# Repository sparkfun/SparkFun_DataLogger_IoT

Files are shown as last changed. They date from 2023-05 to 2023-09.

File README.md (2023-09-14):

SparkFun DataLogger IoT
========================================

SparkFun DataLogger IoT (https://www.sparkfun.com/products/22462)

[*SparkFun DataLogger IoT (DEV-22462)*](https://www.sparkfun.com/products/22462)

<Basic description of the part.>

Repository Contents
-------------------

<!-- * **/Enclosure** - Enclosure files --> 
* **/Examples** - Test code 
* **/Hardware** - Eagle design files (.brd, .sch)
* **/Production** - Production panel files (.brd)

Documentation
--------------
* **[Hookup Guide](https://docs.sparkfun.com/SparkFun_DataLogger/)** - Basic hookup guide for the DataLogger IoT.
* **[Firmware](https://github.com/sparkfun/SparkFun_DataLogger/)** - Repo for the Datalogger IoT Firmware

Product Versions
----------------
* [DEV-22462](https://www.sparkfun.com/products/22462) - Initial Release

Version History
---------------
* v1.1 - Initial Release

License Information
-------------------

This hardware and the hardware test sketches contained in this GitHub repo are _**open source**_!

Please review the LICENSE.md file for license information. 

If you have any questions or concerns on licensing, please contact technical support on our [SparkFun forums](https://forum.sparkfun.com/viewforum.php?f=152).

Distributed as-is; no warranty is given.

- Your friends at SparkFun.

_<COLLABORATION CREDIT>_

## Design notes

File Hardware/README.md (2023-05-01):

SparkFun <PRODUCT NAME> Design Files
=====================================

The .sch and .brd files hare are Eagle CAD schematic and PCB design files from SparkFun Electronics.
A freeware version of Autodesk Eagle can be found [here](https://www.autodesk.com/products/eagle/free-download).

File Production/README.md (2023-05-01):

SparkFun <PRODUCT NAME> Production Files
=========================================

These are the production files SparkFun uses for printing PCBs.

License Information
-------------------
This product is open source! 

The hardware is released under [Creative Commons ShareAlike 4.0 International](https://creativecommons.org/licenses/by-sa/4.0/).

Please use, reuse, and modify these files as you see fit. Please maintain attribution to SparkFun Electronics and release anything derivative under the same license.

Distributed as-is; no warranty is given.

- Your friends at SparkFun.

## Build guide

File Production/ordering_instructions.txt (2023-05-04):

panel size, 116x155mm
PCB thickness, 1.6mm
number of layers, 4
controlled impedance, JLC7628
material, TG155
soldermask color, Red
silkscreen color, White
oz copper, 1oz
finish, HASL lead free
stencils, top+bottom
pcs per panel, 6
min trace width, 0.1524mm / 0.0060in
min drill size, 0.3000mm / 0.0118in
filename to layer stackup 1/2/3/4: GTL, GL2, GL3, GBL

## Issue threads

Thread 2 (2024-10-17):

Not possible to get higher accelerometer sampling rates using Datalogger IoT

Mohrlund, 2024-10-17:
### Subject of the issue
Not possible to get higher sample rates

### Your workbench
* What development board or microcontroller are you using? DataLogger IoT
* What version of hardware or breakout board are you using? See https://community.sparkfun.com/t/slow-sampling-rate-with-sparkfun-datalogger-iot-sparkfun-6dof-imu-breakout-ism330/61119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
* How is the breakout board wired to your microcontroller? QWIIK cable
* How is everything being powered? Tried both battery and lab agg
* Are there any additional details that may help us help you? See https://community.sparkfun.com/t/slow-sampling-rate-with-sparkfun-datalogger-iot-sparkfun-6dof-imu-breakout-ism330/61119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

### Steps to reproduce
Tell us how to reproduce this issue. Please post stripped down example code demonstrating your issue.
See https://community.sparkfun.com/t/slow-sampling-rate-with-sparkfun-datalogger-iot-sparkfun-6dof-imu-breakout-ism330/61119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

### Expected behavior
Tell us what should happen
I can't log data at the higher sampling rates available in the Datalogger IoT setup menu

### Actual behavior
Tell us what happens instead
See https://community.sparkfun.com/t/slow-sampling-rate-with-sparkfun-datalogger-iot-sparkfun-6dof-imu-breakout-ism330/61119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

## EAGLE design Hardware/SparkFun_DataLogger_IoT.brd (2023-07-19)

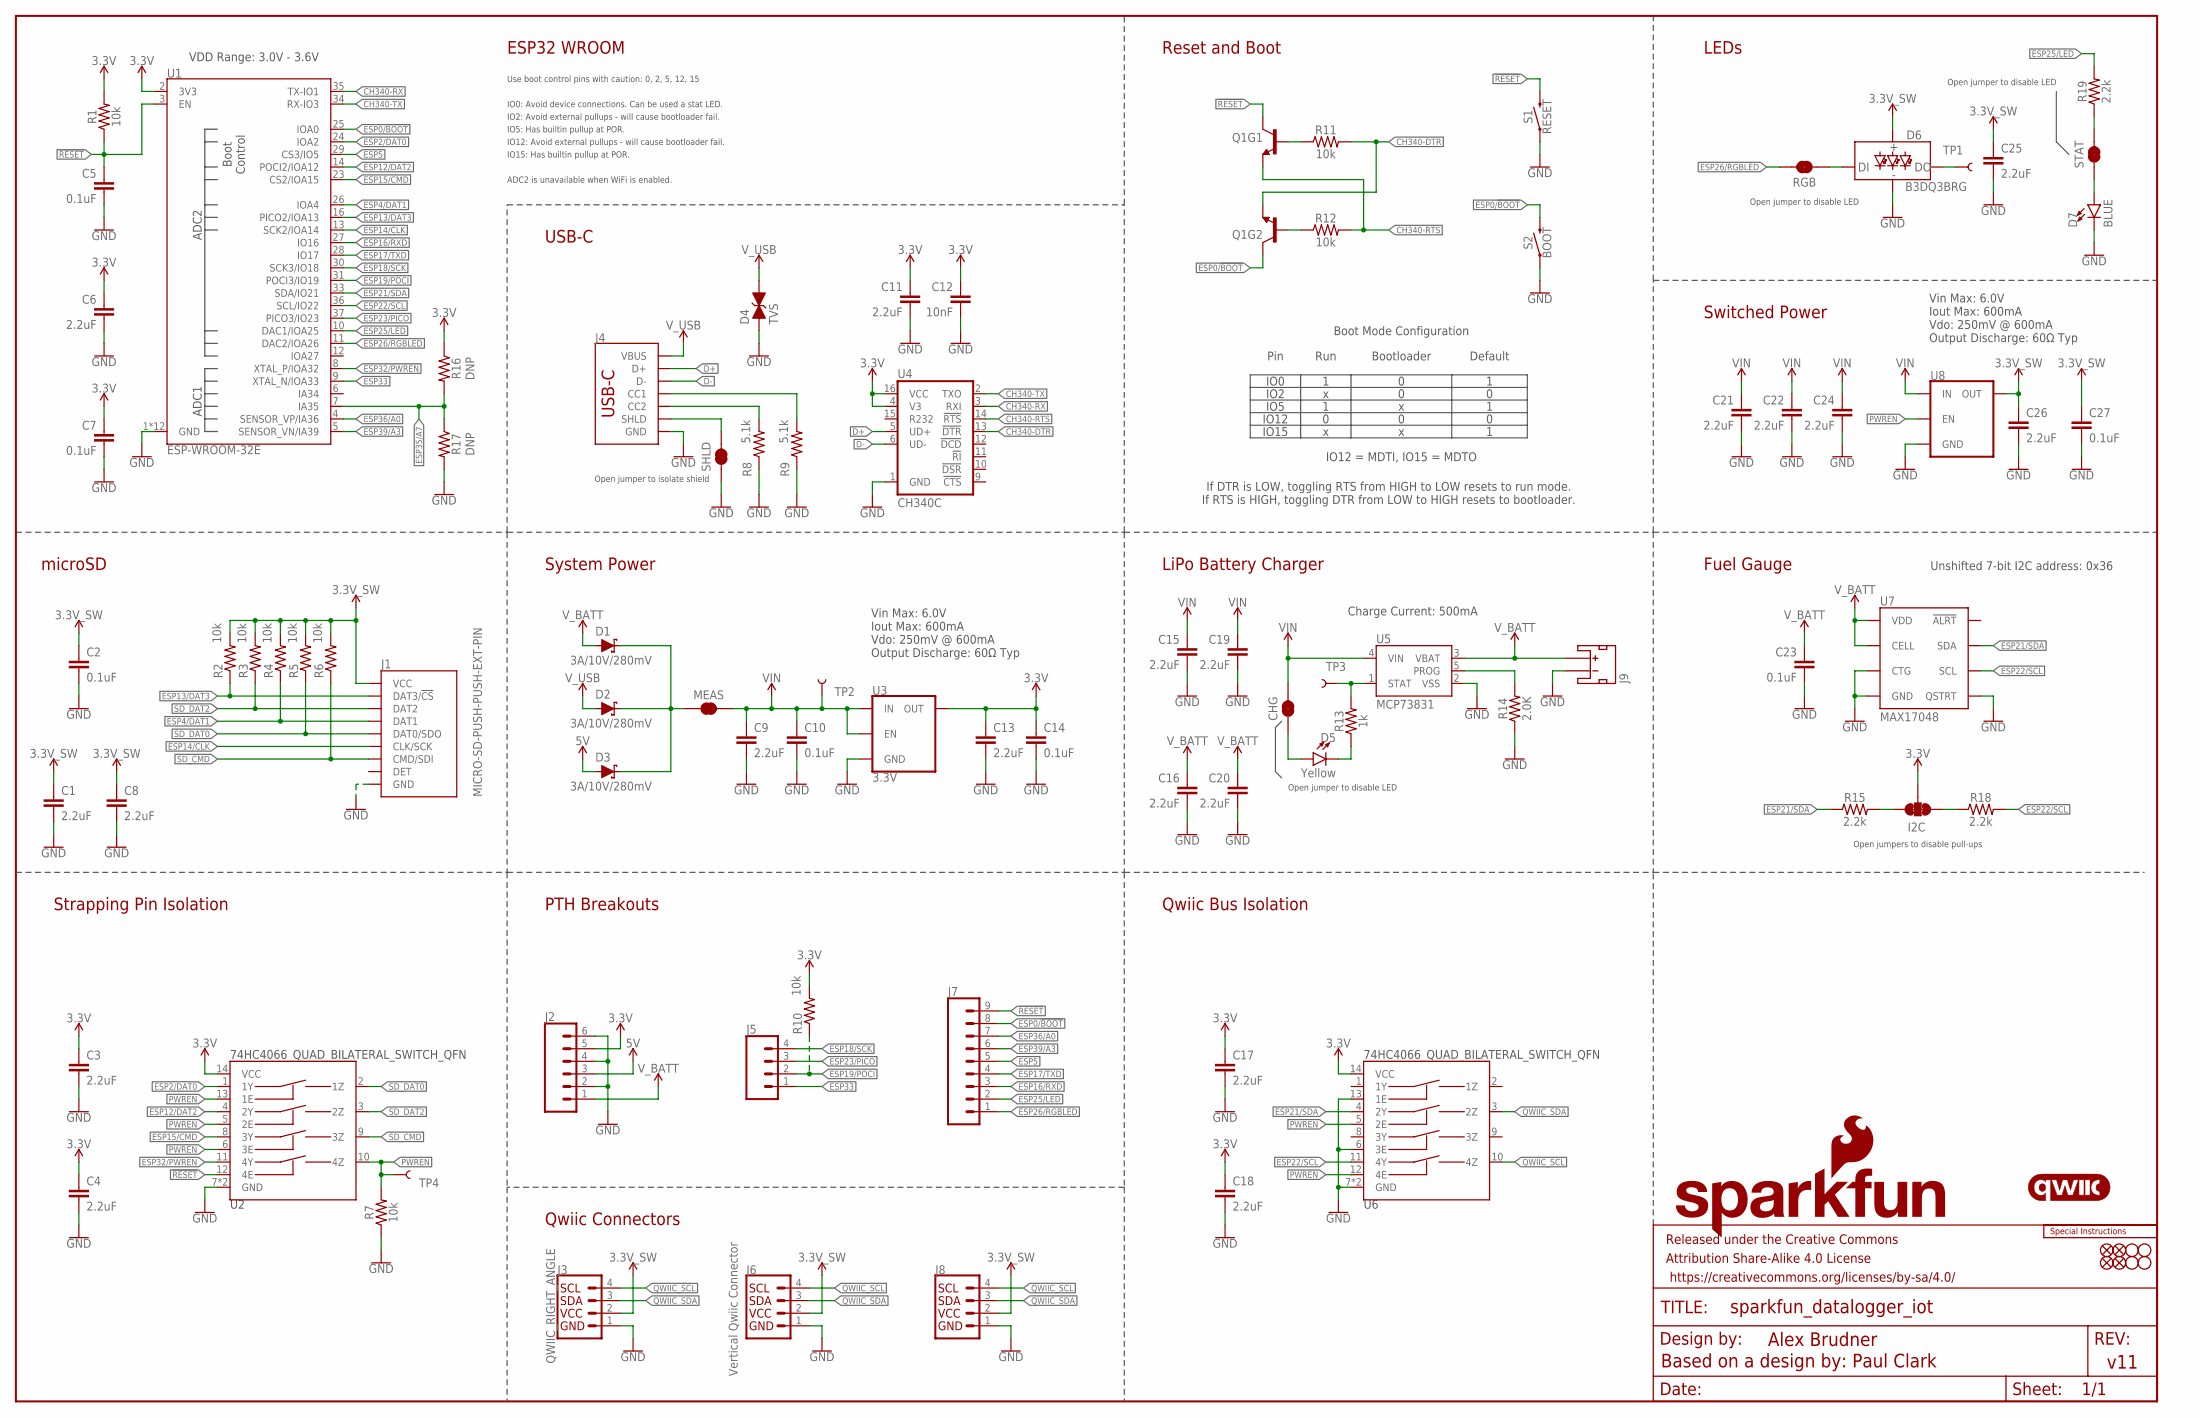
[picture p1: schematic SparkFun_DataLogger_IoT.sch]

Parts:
C1, C3, C4, C6, C8, C9, C11, C13, C15, C16, C17, C18, C19, C20, C21, C22, C24, C25, C26: 2.2uF; 0402-TIGHT
C2, C5, C7, C10, C14, C23, C27: 0.1uF; 0402-TIGHT
C12: 10nF; 0402-TIGHT
CHG: JUMPER-SMT_2_NC_TRACE_SILK; SMT-JUMPER_2_NC_TRACE_SILK
D1, D2, D3: 3A/10V/280mV; SOD-323
D4: TVS; 0603
D5: Yellow; LED-0603
D6: B3DQ3BRG
D7: BLUE; LED-0603
FD1, FD2, FD3, FD4: FIDUCIAL1X2; FIDUCIAL-1X2
FRAME1: FRAME-LEDGER; CREATIVE_COMMONS
H1, H2, H3, H4: STAND-OFFTIGHT; STAND-OFF-TIGHT
I2C: JUMPER-SMT_3_2-NC_TRACE_SILK; SMT-JUMPER_3_2-NC_TRACE_SILK
J1: MICRO-SD-PUSH-PUSH-EXT-PIN; MICROSD-EXTERNALPIN
J2: CONN_06NO_SILK_NO_POP; 1X06_NO_SILK
J3: QWIIC_RIGHT_ANGLE; JST04_1MM_RA
J4: USB_C_4-LAYER_PADS; USB-C-16P_4LAYER-PADS
J5: CONN_041X04_NO_SILK_NO_POP; 1X04_NO_SILK
J6: Vertical Qwiic Connector; JST04_1MM_VERT
J7: CONN_09NO_SILK; 1X09_NO_SILK
J8: I2C_STANDARD_NO_SILK; 1X04_NO_SILK
J9: JST_2MM_MALE; JST-2-SMD
LOGO1: SFE_LOGO_NAME.2_INCH; SFE_LOGO_NAME_.2
LOGO2: SFE_LOGO_FLAME.2_INCH; SFE_LOGO_FLAME_.2
LOGO3: SPECIAL_INSTRUCTIONS-ORDERING; ORDERING_INSTRUCTIONS
LOGO4: QWIIC_LOGO_6MM; QWIIC_6MM
MEAS: JUMPER-COMBO_2_NC_TRACE; COMBO-JUMPER_2_NC_TRACE
Q1: TRANS_NPN_DUAL-MBT3904DW1T1; SC70-6
R1, R2, R3, R4, R5, R6, R7, R10, R11, R12: 10k; 0402-TIGHT
R8, R9: 5.1k; 0402-TIGHT
R13: 1k; 0402-TIGHT
R14: 2.0K; 0402-TIGHT
R15, R18, R19: 2.2k; 0402-TIGHT
R16, R17: DNP; 0402-TIGHT_NO_CREAM
RGB: JUMPER-SMT_2_NC_TRACE_SILK; SMT-JUMPER_2_NC_TRACE_SILK
S1: RESET; TACTILE_SWITCH_SMD_RIGHT_ANGLE
S2: BOOT; TACTILE_SWITCH_SMD_RIGHT_ANGLE
SHLD: JUMPER-SMT_2_NC_TRACE_SILK; SMT-JUMPER_2_NC_TRACE_SILK
STAT: JUMPER-SMT_2_NC_TRACE_SILK; SMT-JUMPER_2_NC_TRACE_SILK
TP1, TP2, TP3, TP4: TEST-POINT3X5; PAD.03X.05
U1: ESP-WROOM-32E; ESP-WROOM-32D-NARROW
U2, U6: 74HC4066_QUAD_BILATERAL_SWITCH_QFN; 14-QFN
U3, U8: 3.3V; SOT23-5
U4: CH340C; SO016
U5: MCP73831; SOT23-5
U7: MAX17048; DFN-8

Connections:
3.3V: C3.1, C4.1, C6.1, C7.1, C11.1, C12.1, C13.1, C14.1, C17.1, C18.1, I2C.2, J2.5, R1.2, R10.2, R16.1, U1.2 (3V3), U2.14 (VCC), U3.5 (OUT), U4.4 (V3), U4.16 (VCC), U6.14 (VCC)
3.3V_SW: C1.1, C2.1, C8.1, C25.1, C26.1, C27.1, D6.2 (VCC), J1.4 (VCC), J3.2, J6.2, J8.2, R2.2, R3.2, R4.2, R5.2, R6.2, U8.5 (OUT)
5V: D3.A, J2.3
!RESET!: C5.1, J7.9, Q1.3 (C), R1.1, S1.2, U1.3 (EN), U2.12 (4E)
CH340-DTR: Q1.1 (E), R11.2, U4.13 (!DTR)
CH340-RTS: Q1.4 (E), R12.2, U4.14 (!RTS)
CH340-RX: U1.35 (TX-IO1), U4.3 (RXI)
CH340-TX: U1.34 (RX-IO3), U4.2 (TXO)
D+: J4.A6 (D+), J4.B6 (D+), U4.5 (UD+)
D-: J4.A7 (D-), J4.B7 (D-), U4.6 (UD-)
ESP0/!BOOT!: J7.8, Q1.6 (C), S2.2, U1.25 (IOA0)
ESP2/DAT0: U1.24 (IOA2), U2.1 (1Y)
ESP4/DAT1: J1.8 (DAT1), R4.1, U1.26 (IOA4)
ESP5: J7.5, U1.29 (CS3/IO5)
ESP12/DAT2: U1.14 (POCI2/IOA12), U2.4 (2Y)
ESP13/DAT3: J1.2 (DAT3/!CS!), R2.1, U1.16 (PICO2/IOA13)
ESP14/CLK: J1.5 (CLK/SCK), U1.13 (SCK2/IOA14)
ESP15/CMD: U1.23 (CS2/IOA15), U2.8 (3Y)
ESP16/RXD: J7.3, U1.27 (IO16)
ESP17/TXD: J7.4, U1.28 (IO17)
ESP18/SCK: J5.4, U1.30 (SCK3/IO18)
ESP19/POCI: J5.2, R10.1, U1.31 (POCI3/IO19)
ESP21/SDA: R15.1, U1.33 (SDA/IO21), U6.4 (2Y), U7.8 (SDA)
ESP22/SCL: R18.2, U1.36 (SCL/IO22), U6.11 (4Y), U7.7 (SCL)
ESP23/PICO: J5.3, U1.37 (PICO3/IO23)
ESP25/LED: J7.2, R19.2, U1.10 (DAC1/IOA25)
ESP26/RGBLED: J7.1, RGB.2, U1.11 (DAC2/IOA26)
ESP32/PWREN: U1.8 (XTAL_P/IOA32), U2.11 (4Y)
ESP33: J5.1, U1.9 (XTAL_N/IOA33)
ESP35/A7: R16.2, R17.1, U1.7 (IA35)
ESP36/A0: J7.7, U1.4 (SENSOR_VP/IA36)
ESP39/A3: J7.6, U1.5 (SENSOR_VN/IA39)
GND: C1.2, C2.2, C3.2, C4.2, C5.2, C6.2, C7.2, C8.2, C9.2, C10.2, C11.2, C12.2, C13.2, C14.2, C15.2, C16.2, C17.2, C18.2, C19.2, C20.2, C21.2, C22.2, C23.2, C24.2, C25.2, C26.2, C27.2, D4.1 (A), D6.1 (GND), D7.C, J1.6 (GND), J1.10 (GND), J1.11 (GND), J1.12 (GND), J1.13 (GND), J2.2, J2.4, J2.6, J3.1, J4.GND, J4.GND2 (GND), J6.1, J8.1, J9.1 (-), R7.1, R8.1, R9.1, R14.1, R17.2, S1.1, S2.1, SHLD.1, U1.1 (GND), U1.15 (GND), U1.38 (GND), U1.GND1 (GND), U1.GNDT1 (GND), U1.GNDT2 (GND), U1.GNDT3 (GND), U1.GNDT4 (GND), U1.GNDT5 (GND), U1.GNDT6 (GND), U1.GNDT7 (GND), U1.GNDT8 (GND), U2.7 (GND), U2.EPAD (GND), U3.2 (GND), U4.1 (GND), U5.2 (VSS), U6.6 (3E), U6.7 (GND), U6.13 (1E), U6.EPAD (GND), U7.1 (CTG), U7.4 (GND), U7.6 (QSTRT), U7.9 (GND), U8.2 (GND)
unnamed: J4.B5 (CC2), R8.2
unnamed: J4.A5 (CC1), R9.2
unnamed: D1.C, D2.C, D3.C, MEAS.1, MEAS.3 (1)
unnamed: Q1.2 (B), R12.1
unnamed: Q1.5 (B), R11.1
unnamed: R19.1, STAT.2
unnamed: D6.4 (DO), TP1.1
unnamed: CHG.1, D5.A
unnamed: D5.C, R13.1
unnamed: R13.2, TP3.1, U5.1 (STAT)
unnamed: R14.2, U5.5 (PROG)
unnamed: D6.3 (DI), RGB.1
unnamed: D7.A, STAT.1
unnamed: I2C.1, R18.1
unnamed: I2C.3, R15.2
PWREN: R7.2, TP4.1, U2.5 (2E), U2.6 (3E), U2.10 (4Z), U2.13 (1E), U6.5 (2E), U6.12 (4E), U8.3 (EN)
QWIIC_SCL: J3.4, J6.4, J8.4, U6.10 (4Z)
QWIIC_SDA: J3.3, J6.3, J8.3, U6.3 (2Z)
SD_CMD: J1.3 (CMD/SDI), R6.1, U2.9 (3Z)
SD_DAT0: J1.7 (DAT0/SDO), R5.1, U2.2 (1Z)
SD_DAT2: J1.1 (DAT2), R3.1, U2.3 (2Z)
SHIELD: J4.SHLD1 (SHLD), J4.SHLD2 (SHLD), J4.SHLD3 (SHLD), J4.SHLD4 (SHLD), SHLD.2
VIN: C9.1, C10.1, C15.1, C19.1, C21.1, C22.1, C24.1, CHG.2, MEAS.2, MEAS.4 (2), TP2.1, U3.1 (IN), U3.3 (EN), U5.4 (VIN), U8.1 (IN)
V_BATT: C16.1, C20.1, C23.1, D1.A, J2.1, J9.2 (+), U5.3 (VBAT), U7.2 (CELL), U7.3 (VDD)
V_USB: D2.A, D4.2 (C), J4.VBUS1 (VBUS), J4.VBUS2 (VBUS)

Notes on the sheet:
ESP32 WROOM
USB-C
Reset and Boot
LEDs
Switched Power
Fuel Gauge
LiPo Battery Charger
System Power
microSD
Strapping Pin Isolation
Qwiic Bus Isolation
PTH Breakouts
Charge Current: 500mA
VDD Range: 3.0V - 3.6V
Vin Max: 6.0V Iout Max: 600mA Vdo: 250mV @ 600mA Output Discharge: 60Ω Typ
If DTR is LOW, toggling RTS from HIGH to LOW resets to run mode. If RTS is HIGH, toggling DTR from LOW to HIGH resets to bootloader.
Pin
IO0
IO2
IO12
IO15
IO5
Run
Bootloader
Default
IO12 = MDTI, IO15 = MDTO
Boot Mode Configuration
IO0: Avoid device connections. Can be used a stat LED.
ADC2 is unavailable when WiFi is enabled.
IO12: Avoid external pullups - will cause bootloader fail.
Use boot control pins with caution: 0, 2, 5, 12, 15
IO2: Avoid external pullups - will cause bootloader fail.
IO15: Has builtin pullup at POR.
IO5: Has builtin pullup at POR.
Open jumpers to disable pull-ups
Open jumper to disable LED
Open jumper to isolate shield
Based on a design by: Paul Clark
Qwiic Connectors
TP2

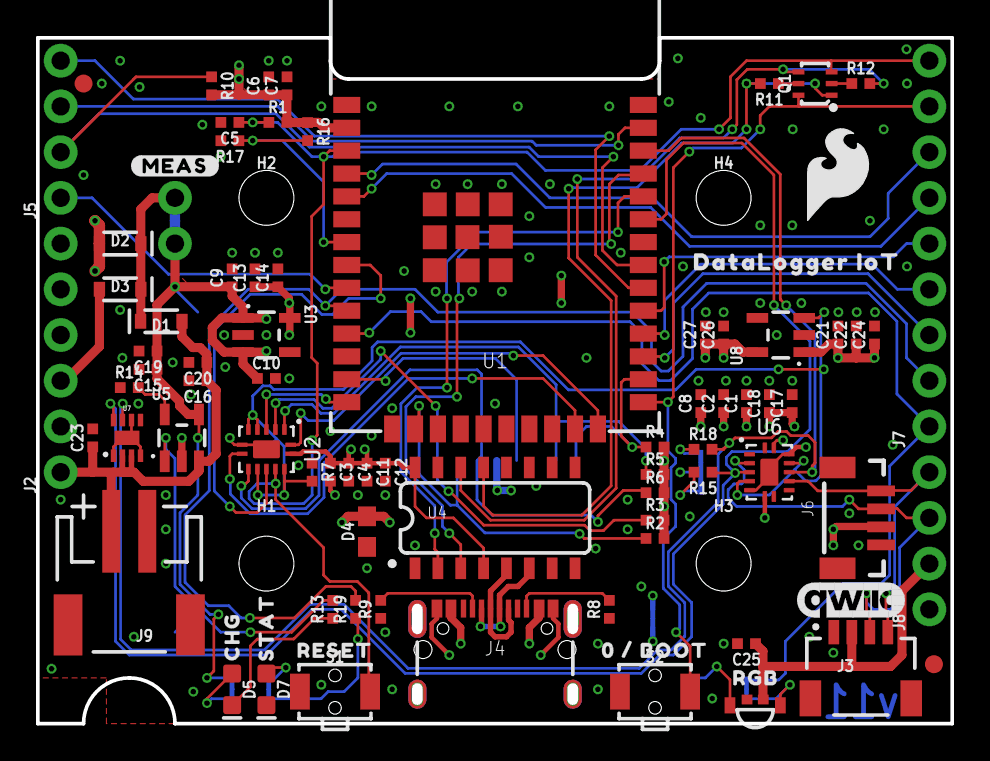
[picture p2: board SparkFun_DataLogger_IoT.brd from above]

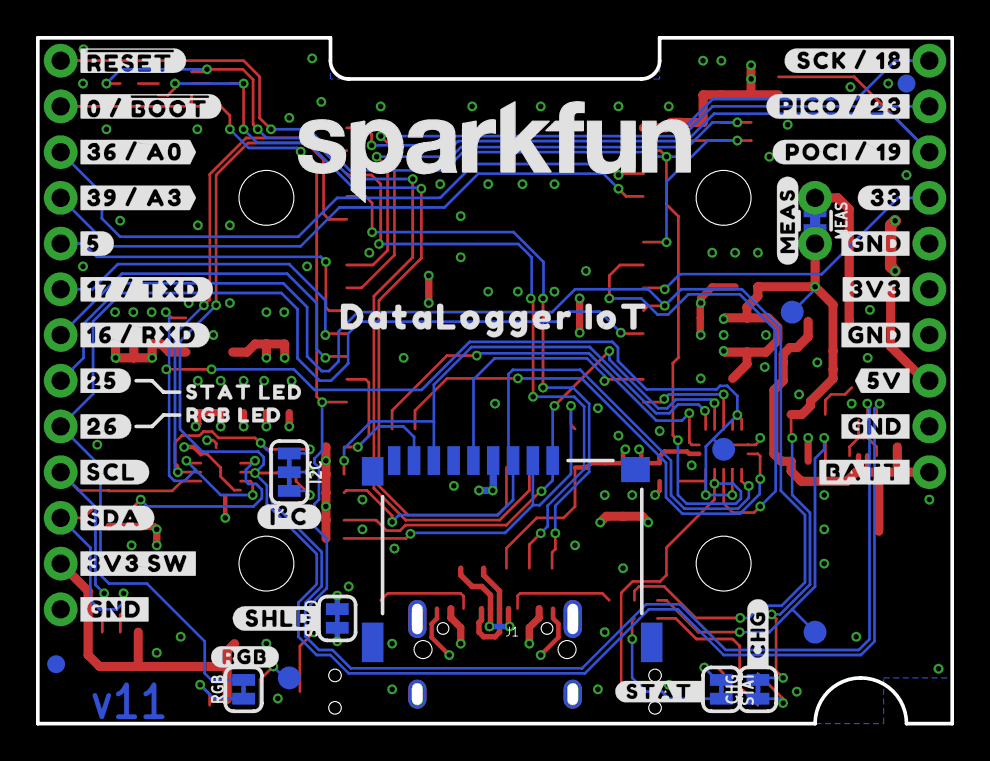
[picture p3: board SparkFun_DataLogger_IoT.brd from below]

Board: 4 copper layers, 50.8 x 38.1 mm, 136 parts (47 on the bottom side), 58 nets.

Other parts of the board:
U$1: DATALOGGER_IOT5
U$2: RESET0
U$3: STAT0
U$4: CHG0
U$5: #STAT_#0
U$6: #RGB#0
U$7: 0_#_BOOT0
U$8: #_CHG#0
U$9, U$10: #MEAS#0
U$11: RGB0
U$12: #5#0
U$13: SFE_LOGO_FLAME_STOP_.1
U$14: DATALOGGER_IOT2
U$16: ##RESET##0
U$17: #0_#_#BOOT##0
U$18: #36_#_A0#0
U$19: #39_#_A3#0
U$21: #17_#_TXD#0
U$22: #16_#_RXD#0
U$23: #25#0
U$24: #26#0
U$25: #SCL#0
U$26: #SDA#0
U$27: #3V3_SW#0
U$28: #GND#0
U$29, U$30, U$31: #GND#1
U$32: #BATT#0
U$33: #5V#0
U$34: #3V3#0
U$35: #33#0
U$36: #POCI_#_19#0
U$37: #PICO_#_23#0
U$38: #SCK_#_18#0
U$45: #SHLD#0
U$46: #I�C#0
U$47: STAT_LED0
U$48: RGB_LED0

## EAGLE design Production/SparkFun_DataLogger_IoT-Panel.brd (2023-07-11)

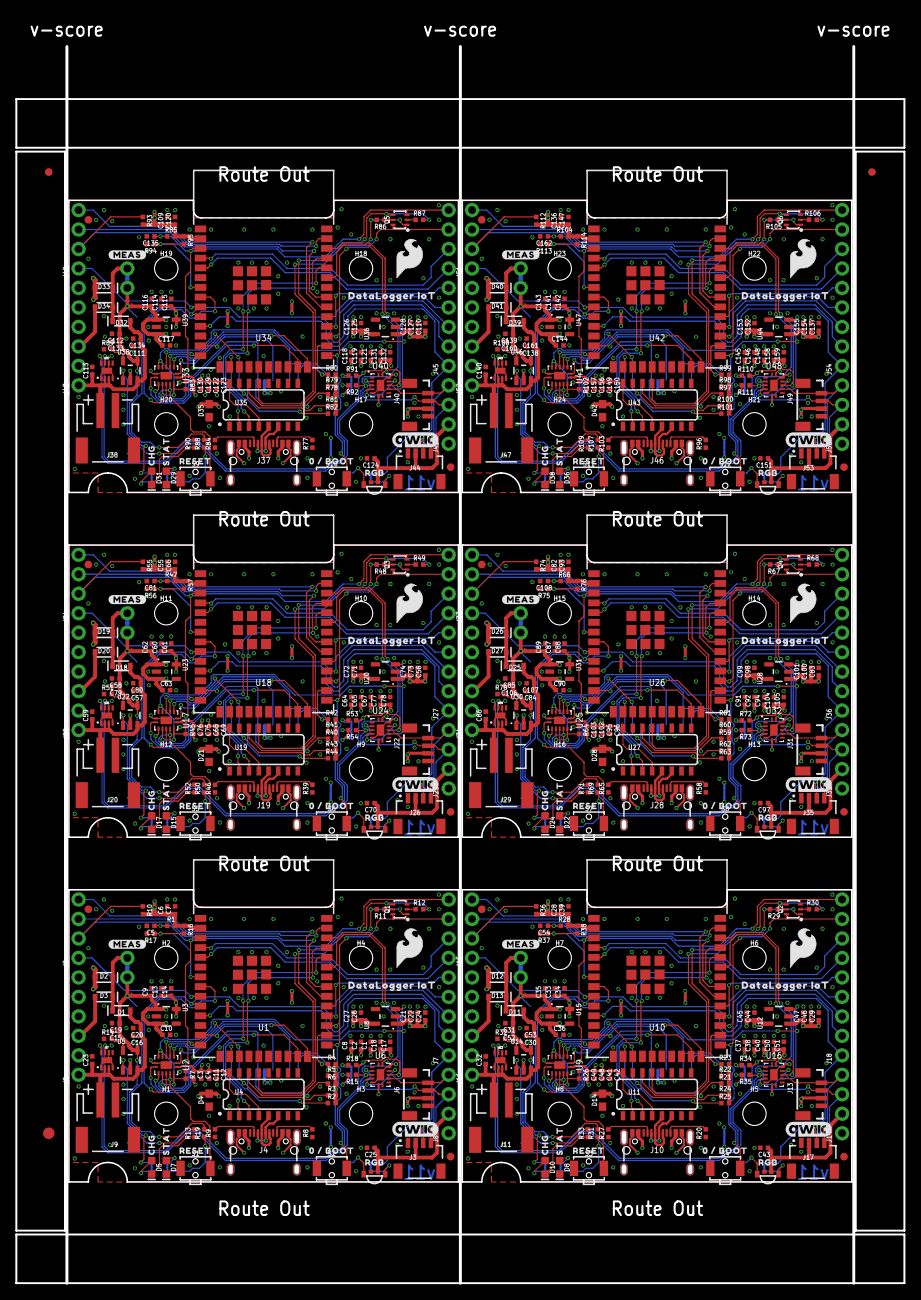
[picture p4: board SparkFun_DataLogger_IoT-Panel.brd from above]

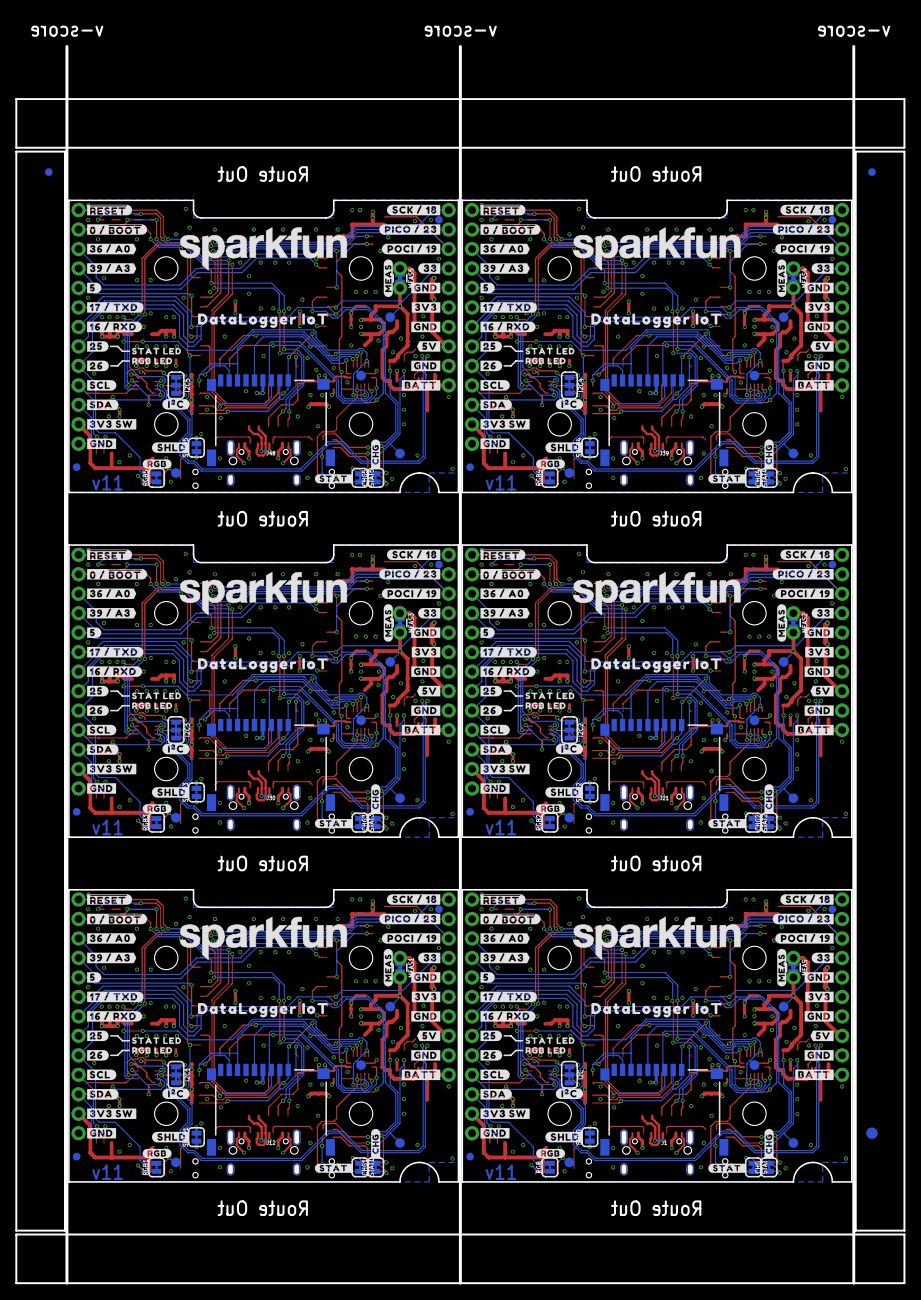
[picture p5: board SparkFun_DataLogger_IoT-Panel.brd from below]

Board: 4 copper layers, 115.8 x 161.3 mm, 810 parts (285 on the bottom side), 348 nets.

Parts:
C1, C3, C4, C6, C8, C9, C11, C13, C15, C16, C17, C18, C19, C20, C21, C22, C24, C25, C26, C28, C29, C30, C31, C33, C35, C37, C40, C41, C43, C44, C46, C47, C48, C49, C50, C51, C52, C53, C55, C56, C57, C58, C60, C62, C64, C67, C68, C70, C71, C73, C74, C75, C76, C77, C78, C79, C80, C82, C83, C84, C85, C87, C89, C91, C94, C95, C97, C98, C100, C101, C102, C103, C104, C105, C106, C107, C109, C110, C111, C112, C114, C116, C118, C121, C122, C124, C125, C127, C128, C129, C130, C131, C132, C133, C134, C136, C137, C138, C139, C141, C143, C145, C148, C149, C151, C152, C154, C155, C156, C157, C158, C159, C160, C161: 2.2uF; 0402-TIGHT
C2, C5, C7, C10, C14, C23, C27, C32, C34, C36, C38, C39, C45, C54, C59, C61, C63, C65, C66, C72, C81, C86, C88, C90, C92, C93, C99, C108, C113, C115, C117, C119, C120, C126, C135, C140, C142, C144, C146, C147, C153, C162: 0.1uF; 0402-TIGHT
C12, C42, C69, C96, C123, C150: 10nF; 0402-TIGHT
CHG, CHG1, CHG2, CHG3, CHG4, CHG5: JUMPER-SMT_2_NC_TRACE_SILK; SMT-JUMPER_2_NC_TRACE_SILK
D1, D2, D3, D11, D12, D13, D18, D19, D20, D25, D26, D27, D32, D33, D34, D39, D40, D41: 3A/10V/280mV; SOD-323
D4, D14, D21, D28, D35, D42: TVS; 0603
D5, D10, D17, D24, D31, D38: Yellow; LED-0603
D6, D9, D16, D23, D30, D37: B3DQ3BRG
D7, D8, D15, D22, D29, D36: BLUE; LED-0603
E$1, E$2, E$3, E$4: FIDUCIAL-1X2
E$5, E$6: FIDUCIAL-1.5X3
FD1, FD2, FD3, FD4, FD5, FD6, FD7, FD8, FD9, FD10, FD11, FD12, FD13, FD14, FD15, FD16, FD17, FD18, FD19, FD20, FD21, FD22, FD23, FD24: FIDUCIAL1X2; FIDUCIAL-1X2
H1, H2, H3, H4, H5, H6, H7, H8, H9, H10, H11, H12, H13, H14, H15, H16, H17, H18, H19, H20, H21, H22, H23, H24: STAND-OFFTIGHT; STAND-OFF-TIGHT
I2C, I2C1, I2C2, I2C3, I2C4, I2C5: JUMPER-SMT_3_2-NC_TRACE_SILK; SMT-JUMPER_3_2-NC_TRACE_SILK
J1, J12, J21, J30, J39, J48: MICRO-SD-PUSH-PUSH-EXT-PIN; MICROSD-EXTERNALPIN
J2, J16, J25, J34, J43, J52: 1X06_NO_SILK
J3, J17, J26, J35, J44, J53: QWIIC_RIGHT_ANGLE; JST04_1MM_RA
J4, J10, J19, J28, J37, J46: USB-C-16P_4LAYER-PADS
J5, J8, J14, J15, J23, J24, J32, J33, J41, J42, J50, J51: 1X04_NO_SILK
J6, J13, J22, J31, J40, J49: Vertical Qwiic Connector; JST04_1MM_VERT
J7, J18, J27, J36, J45, J54: 1X09_NO_SILK
J9, J11, J20, J29, J38, J47: JST-2-SMD
LOGO1, LOGO5, LOGO8, LOGO11, LOGO14, LOGO17: SFE_LOGO_NAME.2_INCH; SFE_LOGO_NAME_.2
LOGO2, LOGO6, LOGO9, LOGO12, LOGO15, LOGO18: SFE_LOGO_FLAME.2_INCH; SFE_LOGO_FLAME_.2
LOGO3, LOGO4, LOGO7, LOGO10, LOGO13, LOGO16: QWIIC_LOGO_6MM; QWIIC_6MM
MEAS, MEAS1, MEAS2, MEAS3, MEAS4, MEAS5: JUMPER-COMBO_2_NC_TRACE; COMBO-JUMPER_2_NC_TRACE
Q1, Q2, Q3, Q4, Q5, Q6: SC70-6
R1, R2, R3, R4, R5, R6, R7, R10, R11, R12, R21, R22, R23, R24, R25, R26, R28, R29, R30, R36, R40, R41, R42, R43, R44, R45, R47, R48, R49, R55, R59, R60, R61, R62, R63, R64, R66, R67, R68, R74, R78, R79, R80, R81, R82, R83, R85, R86, R87, R93, R97, R98, R99, R100, R101, R102, R104, R105, R106, R112: 10k; 0402-TIGHT
R8, R9, R20, R27, R39, R46, R58, R65, R77, R84, R96, R103: 5.1k; 0402-TIGHT
R13, R33, R52, R71, R90, R109: 1k; 0402-TIGHT
R14, R32, R51, R70, R89, R108: 2.0K; 0402-TIGHT
R15, R18, R19, R31, R34, R35, R50, R53, R54, R69, R72, R73, R88, R91, R92, R107, R110, R111: 2.2k; 0402-TIGHT
R16, R38, R57, R76, R95, R114: 100k; 0402-TIGHT
R17, R37, R56, R75, R94, R113: 9.1K; 0402-TIGHT
RGB, RGB1, RGB2, RGB3, RGB4, RGB5: JUMPER-SMT_2_NC_TRACE_SILK; SMT-JUMPER_2_NC_TRACE_SILK
S1, S3, S5, S7, S9, S11: RESET; TACTILE_SWITCH_SMD_RIGHT_ANGLE
S2, S4, S6, S8, S10, S12: BOOT; TACTILE_SWITCH_SMD_RIGHT_ANGLE
SHLD, SHLD1, SHLD2, SHLD3, SHLD4, SHLD5: JUMPER-SMT_2_NC_TRACE_SILK; SMT-JUMPER_2_NC_TRACE_SILK
STAT, STAT1, STAT2, STAT3, STAT4, STAT5: JUMPER-SMT_2_NC_TRACE_SILK; SMT-JUMPER_2_NC_TRACE_SILK
TP1, TP2, TP3, TP4, TP5, TP6, TP7, TP8, TP9, TP10, TP11, TP12, TP13, TP14, TP15, TP16, TP17, TP18, TP19, TP20, TP21, TP22, TP23, TP24: TEST-POINT3X5; PAD.03X.05
U1, U10, U18, U26, U34, U42: ESP-WROOM-32E; ESP-WROOM-32D-NARROW
U2, U6, U9, U16, U17, U24, U25, U32, U33, U40, U41, U48: 74HC4066_QUAD_BILATERAL_SWITCH_QFN; 14-QFN
U3, U8, U12, U15, U20, U23, U28, U31, U36, U39, U44, U47: XC6222B331MR-G; SOT23-5
U4, U11, U19, U27, U35, U43: CH340C; SO016
U5, U14, U22, U30, U38, U46: MCP73831; SOT23-5
U7, U13, U21, U29, U37, U45: MAX17048; DFN-8
U$1, U$79, U$119, U$159, U$199, U$239: DATALOGGER_IOT5
U$2, U$15, U$81, U$121, U$161, U$201: RESET0
U$3, U$20, U$82, U$122, U$162, U$202: STAT0
U$4, U$39, U$83, U$123, U$163, U$203: CHG0
U$5, U$72, U$112, U$152, U$192, U$232: #STAT_#0
U$6, U$73, U$113, U$153, U$193, U$233: #RGB#0
U$7, U$70, U$110, U$150, U$190, U$230: 0_#_BOOT0
U$8, U$71, U$111, U$151, U$191, U$231: #_CHG#0
U$9, U$10, U$74, U$75, U$114, U$115, U$154, U$155, U$194, U$195, U$234, U$235: #MEAS#0
U$11, U$76, U$116, U$156, U$196, U$236: RGB0
U$12, U$80, U$120, U$160, U$200, U$240: #5#0
U$13, U$77, U$117, U$157, U$197, U$237: SFE_LOGO_FLAME_STOP_.1
U$14, U$78, U$118, U$158, U$198, U$238: DATALOGGER_IOT2
U$16, U$40, U$84, U$124, U$164, U$204: ##RESET##0
U$17, U$41, U$85, U$125, U$165, U$205: #0_#_#BOOT##0
U$18, U$42, U$86, U$126, U$166, U$206: #36_#_A0#0
U$19, U$43, U$87, U$127, U$167, U$207: #39_#_A3#0
U$21, U$44, U$88, U$128, U$168, U$208: #17_#_TXD#0
U$22, U$49, U$89, U$129, U$169, U$209: #16_#_RXD#0
U$23, U$50, U$90, U$130, U$170, U$210: #25#0
U$24, U$51, U$91, U$131, U$171, U$211: #26#0
U$25, U$52, U$92, U$132, U$172, U$212: #SCL#0
U$26, U$53, U$93, U$133, U$173, U$213: #SDA#0
U$27, U$54, U$94, U$134, U$174, U$214: #3V3_SW#0
U$28, U$55, U$95, U$135, U$175, U$215: #GND#0
U$29, U$30, U$31, U$56, U$57, U$58, U$96, U$97, U$98, U$136, U$137, U$138, U$176, U$177, U$178, U$216, U$217, U$218: #GND#1
U$32, U$59, U$99, U$139, U$179, U$219: #BATT#0
U$33, U$60, U$100, U$140, U$180, U$220: #5V#0
U$34, U$61, U$101, U$141, U$181, U$221: #3V3#0
U$35, U$62, U$102, U$142, U$182, U$222: #33#0
U$36, U$63, U$103, U$143, U$183, U$223: #POCI_#_19#0
U$37, U$64, U$104, U$144, U$184, U$224: #PICO_#_23#0
U$38, U$65, U$105, U$145, U$185, U$225: #SCK_#_18#0
U$45, U$66, U$106, U$146, U$186, U$226: #SHLD#0
U$46, U$67, U$107, U$147, U$187, U$227: #I�C#0
U$47, U$68, U$108, U$148, U$188, U$228: STAT_LED0
U$48, U$69, U$109, U$149, U$189, U$229: RGB_LED0

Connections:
3.3V: C3.1, C4.1, C6.1, C7.1, C11.1, C12.1, C13.1, C14.1, C17.1, C18.1, I2C.2, J2.5, R1.2, R10.2, R16.1, U1.2, U2.14, U3.5, U4.4, U4.16, U6.14
3.3V1: C28.1, C33.1, C34.1, C39.1, C41.1, C42.1, C48.1, C49.1, C50.1, C51.1, I2C1.2, J16.5, R28.2, R36.2, R38.1, U9.14, U10.2, U11.4, U11.16, U15.5, U16.14
3.3V2: C55.1, C60.1, C61.1, C66.1, C68.1, C69.1, C75.1, C76.1, C77.1, C78.1, I2C2.2, J25.5, R47.2, R55.2, R57.1, U17.14, U18.2, U19.4, U19.16, U23.5, U24.14
3.3V3: C82.1, C87.1, C88.1, C93.1, C95.1, C96.1, C102.1, C103.1, C104.1, C105.1, I2C3.2, J34.5, R66.2, R74.2, R76.1, U25.14, U26.2, U27.4, U27.16, U31.5, U32.14
3.3V4: C109.1, C114.1, C115.1, C120.1, C122.1, C123.1, C129.1, C130.1, C131.1, C132.1, I2C4.2, J43.5, R85.2, R93.2, R95.1, U33.14, U34.2, U35.4, U35.16, U39.5, U40.14
3.3V5: C136.1, C141.1, C142.1, C147.1, C149.1, C150.1, C156.1, C157.1, C158.1, C159.1, I2C5.2, J52.5, R104.2, R112.2, R114.1, U41.14, U42.2, U43.4, U43.16, U47.5, U48.14
3.3V_SW: C1.1, C2.1, C8.1, C25.1, C26.1, C27.1, D6.2, J1.4, J3.2, J6.2, J8.2, R2.2, R3.2, R4.2, R5.2, R6.2, U8.5
3.3V_SW1: C37.1, C38.1, C40.1, C43.1, C44.1, C45.1, D9.2, J12.4, J13.2, J14.2, J17.2, R21.2, R22.2, R23.2, R24.2, R25.2, U12.5
3.3V_SW2: C64.1, C65.1, C67.1, C70.1, C71.1, C72.1, D16.2, J21.4, J22.2, J23.2, J26.2, R40.2, R41.2, R42.2, R43.2, R44.2, U20.5
3.3V_SW3: C91.1, C92.1, C94.1, C97.1, C98.1, C99.1, D23.2, J30.4, J31.2, J32.2, J35.2, R59.2, R60.2, R61.2, R62.2, R63.2, U28.5
3.3V_SW4: C118.1, C119.1, C121.1, C124.1, C125.1, C126.1, D30.2, J39.4, J40.2, J41.2, J44.2, R78.2, R79.2, R80.2, R81.2, R82.2, U36.5
3.3V_SW5: C145.1, C146.1, C148.1, C151.1, C152.1, C153.1, D37.2, J48.4, J49.2, J50.2, J53.2, R97.2, R98.2, R99.2, R100.2, R101.2, U44.5
5V: D3.A, J2.3
5V1: D13.A, J16.3
5V2: D20.A, J25.3
5V3: D27.A, J34.3
5V4: D34.A, J43.3
5V5: D41.A, J52.3
!RESET!: C5.1, J7.9, Q1.3, R1.1, S1.2, U1.3, U2.12
!RESET!1: C54.1, J18.9, Q2.3, R28.1, S3.2, U9.12, U10.3
!RESET!2: C81.1, J27.9, Q3.3, R47.1, S5.2, U17.12, U18.3
!RESET!3: C108.1, J36.9, Q4.3, R66.1, S7.2, U25.12, U26.3
!RESET!4: C135.1, J45.9, Q5.3, R85.1, S9.2, U33.12, U34.3
!RESET!5: C162.1, J54.9, Q6.3, R104.1, S11.2, U41.12, U42.3
CH340-DTR: Q1.1, R11.2, U4.13
CH340-DTR1: Q2.1, R29.2, U11.13
CH340-DTR2: Q3.1, R48.2, U19.13
CH340-DTR3: Q4.1, R67.2, U27.13
CH340-DTR4: Q5.1, R86.2, U35.13
CH340-DTR5: Q6.1, R105.2, U43.13
CH340-RTS: Q1.4, R12.2, U4.14
CH340-RTS1: Q2.4, R30.2, U11.14
CH340-RTS2: Q3.4, R49.2, U19.14
CH340-RTS3: Q4.4, R68.2, U27.14
CH340-RTS4: Q5.4, R87.2, U35.14
CH340-RTS5: Q6.4, R106.2, U43.14
CH340-RX: U1.35, U4.3
CH340-RX1: U10.35, U11.3
CH340-RX2: U18.35, U19.3
CH340-RX3: U26.35, U27.3
CH340-RX4: U34.35, U35.3
CH340-RX5: U42.35, U43.3
CH340-TX: U1.34, U4.2
CH340-TX1: U10.34, U11.2
CH340-TX2: U18.34, U19.2
CH340-TX3: U26.34, U27.2
CH340-TX4: U34.34, U35.2
CH340-TX5: U42.34, U43.2
D+: J4.A6, J4.B6, U4.5
D+1: J10.A6, J10.B6, U11.5
D+2: J19.A6, J19.B6, U19.5
D+3: J28.A6, J28.B6, U27.5
D+4: J37.A6, J37.B6, U35.5
D+5: J46.A6, J46.B6, U43.5
D-: J4.A7, J4.B7, U4.6
D-1: J10.A7, J10.B7, U11.6
D-2: J19.A7, J19.B7, U19.6
D-3: J28.A7, J28.B7, U27.6
D-4: J37.A7, J37.B7, U35.6
D-5: J46.A7, J46.B7, U43.6
ESP0/!BOOT!: J7.8, Q1.6, S2.2, U1.25
ESP0/!BOOT!1: J18.8, Q2.6, S4.2, U10.25
ESP0/!BOOT!2: J27.8, Q3.6, S6.2, U18.25
ESP0/!BOOT!3: J36.8, Q4.6, S8.2, U26.25
ESP0/!BOOT!4: J45.8, Q5.6, S10.2, U34.25
ESP0/!BOOT!5: J54.8, Q6.6, S12.2, U42.25
ESP1: J15.1, U10.9
ESP2: J18.5, U10.29
ESP2/DAT0: U1.24, U2.1
ESP2/DAT1: U9.1, U10.24
ESP2/DAT2: U17.1, U18.24
ESP2/DAT3: U25.1, U26.24
ESP2/DAT4: U33.1, U34.24
ESP2/DAT5: U41.1, U42.24
ESP3: J24.1, U18.9
ESP4: J27.5, U18.29
ESP4/DAT1: J1.8, R4.1, U1.26
ESP4/DAT2: J12.8, R23.1, U10.26
ESP4/DAT3: J21.8, R42.1, U18.26
ESP4/DAT4: J30.8, R61.1, U26.26
ESP4/DAT5: J39.8, R80.1, U34.26
ESP4/DAT6: J48.8, R99.1, U42.26
ESP5: J7.5, U1.29
ESP6: J33.1, U26.9
ESP7: J36.5, U26.29
ESP8: J42.1, U34.9
ESP9: J45.5, U34.29
ESP10: J51.1, U42.9
ESP11: J54.5, U42.29
ESP12/DAT1: U9.4, U10.14
ESP12/DAT2: U1.14, U2.4
ESP12/DAT3: U17.4, U18.14
ESP12/DAT4: U25.4, U26.14
ESP12/DAT5: U33.4, U34.14
ESP12/DAT6: U41.4, U42.14
ESP13/DAT1: J12.2, R25.1, U10.16
ESP13/DAT2: J21.2, R44.1, U18.16
ESP13/DAT3: J1.2, R2.1, U1.16
ESP13/DAT4: J30.2, R63.1, U26.16
ESP13/DAT5: J39.2, R82.1, U34.16
ESP13/DAT6: J48.2, R101.1, U42.16
ESP14/CLK: J1.5, U1.13
ESP14/CLK1: J12.5, U10.13
ESP14/CLK2: J21.5, U18.13
ESP14/CLK3: J30.5, U26.13
ESP14/CLK4: J39.5, U34.13
ESP14/CLK5: J48.5, U42.13
ESP15/CMD: U1.23, U2.8
ESP15/CMD1: U9.8, U10.23
ESP15/CMD2: U17.8, U18.23
ESP15/CMD3: U25.8, U26.23
ESP15/CMD4: U33.8, U34.23
ESP15/CMD5: U41.8, U42.23
ESP16/RXD: J7.3, U1.27
ESP16/RXD1: J18.3, U10.27
ESP16/RXD2: J27.3, U18.27
ESP16/RXD3: J36.3, U26.27
ESP16/RXD4: J45.3, U34.27
ESP16/RXD5: J54.3, U42.27
ESP17/TXD: J7.4, U1.28
ESP17/TXD1: J18.4, U10.28
ESP17/TXD2: J27.4, U18.28
ESP17/TXD3: J36.4, U26.28
ESP17/TXD4: J45.4, U34.28
ESP17/TXD5: J54.4, U42.28
ESP18/SCK: J5.4, U1.30
ESP18/SCK1: J15.4, U10.30
ESP18/SCK2: J24.4, U18.30
ESP18/SCK3: J33.4, U26.30
ESP18/SCK4: J42.4, U34.30
ESP18/SCK5: J51.4, U42.30
ESP19/POCI: J5.2, R10.1, U1.31
ESP19/POCI1: J15.2, R36.1, U10.31
ESP19/POCI2: J24.2, R55.1, U18.31
ESP19/POCI3: J33.2, R74.1, U26.31
ESP19/POCI4: J42.2, R93.1, U34.31
ESP19/POCI5: J51.2, R112.1, U42.31
ESP21/SDA: R15.1, U1.33, U6.4, U7.8
ESP21/SDA1: R35.1, U10.33, U13.8, U16.4
ESP21/SDA2: R54.1, U18.33, U21.8, U24.4
ESP21/SDA3: R73.1, U26.33, U29.8, U32.4
ESP21/SDA4: R92.1, U34.33, U37.8, U40.4
ESP21/SDA5: R111.1, U42.33, U45.8, U48.4
ESP22/SCL: R18.2, U1.36, U6.11, U7.7
ESP22/SCL1: R34.2, U10.36, U13.7, U16.11
ESP22/SCL2: R53.2, U18.36, U21.7, U24.11
ESP22/SCL3: R72.2, U26.36, U29.7, U32.11
ESP22/SCL4: R91.2, U34.36, U37.7, U40.11
ESP22/SCL5: R110.2, U42.36, U45.7, U48.11
ESP23/PICO: J5.3, U1.37
ESP23/PICO1: J15.3, U10.37
ESP23/PICO2: J24.3, U18.37
ESP23/PICO3: J33.3, U26.37
ESP23/PICO4: J42.3, U34.37
ESP23/PICO5: J51.3, U42.37
ESP25/LED: J7.2, R19.2, U1.10
ESP25/LED1: J18.2, R31.2, U10.10
ESP25/LED2: J27.2, R50.2, U18.10
ESP25/LED3: J36.2, R69.2, U26.10
ESP25/LED4: J45.2, R88.2, U34.10
ESP25/LED5: J54.2, R107.2, U42.10
ESP26/RGBLED: J7.1, RGB.2, U1.11
ESP26/RGBLED1: J18.1, RGB1.2, U10.11
ESP26/RGBLED2: J27.1, RGB2.2, U18.11
ESP26/RGBLED3: J36.1, RGB3.2, U26.11
ESP26/RGBLED4: J45.1, RGB4.2, U34.11
ESP26/RGBLED5: J54.1, RGB5.2, U42.11
ESP32/PWREN: U1.8, U2.11
ESP32/PWREN1: U9.11, U10.8
ESP32/PWREN2: U17.11, U18.8
ESP32/PWREN3: U25.11, U26.8
ESP32/PWREN4: U33.11, U34.8
ESP32/PWREN5: U41.11, U42.8
ESP33: J5.1, U1.9
ESP35/A1: R37.1, R38.2, U10.7
ESP35/A2: R56.1, R57.2, U18.7
ESP35/A3: R75.1, R76.2, U26.7
ESP35/A4: R94.1, R95.2, U34.7
ESP35/A5: R113.1, R114.2, U42.7
ESP35/A7: R16.2, R17.1, U1.7
ESP36/A0: J7.7, U1.4
ESP36/A1: J18.7, U10.4
ESP36/A2: J27.7, U18.4
ESP36/A3: J36.7, U26.4
ESP36/A4: J45.7, U34.4
ESP36/A5: J54.7, U42.4
ESP39/A1: J18.6, U10.5
ESP39/A2: J27.6, U18.5
ESP39/A3: J7.6, U1.5
ESP39/A4: J36.6, U26.5
ESP39/A5: J45.6, U34.5
ESP39/A6: J54.6, U42.5
GND: C1.2, C2.2, C3.2, C4.2, C5.2, C6.2, C7.2, C8.2, C9.2, C10.2, C11.2, C12.2, C13.2, C14.2, C15.2, C16.2, C17.2, C18.2, C19.2, C20.2, C21.2, C22.2, C23.2, C24.2, C25.2, C26.2, C27.2, D4.1, D6.1, D7.C, J1.6, J1.10, J1.11, J1.12, J1.13, J2.2, J2.4, J2.6, J3.1, J4.GND, J4.GND2, J6.1, J8.1, J9.1, R7.1, R8.1, R9.1, R14.1, R17.2, S1.1, S2.1, SHLD.1, U1.1, U1.15, U1.38, U1.GND1, U1.GNDT1, U1.GNDT2, U1.GNDT3, U1.GNDT4, U1.GNDT5, U1.GNDT6, U1.GNDT7, U1.GNDT8, U2.7, U2.EPAD, U3.2, U4.1, U5.2, U6.6, U6.7, U6.13, U6.EPAD, U7.1, U7.4, U7.6, U7.9, U8.2
GND1: C28.2, C29.2, C30.2, C31.2, C32.2, C33.2, C34.2, C35.2, C36.2, C37.2, C38.2, C39.2, C40.2, C41.2, C42.2, C43.2, C44.2, C45.2, C46.2, C47.2, C48.2, C49.2, C50.2, C51.2, C52.2, C53.2, C54.2, D8.C, D9.1, D14.1, J10.GND, J10.GND2, J11.1, J12.6, J12.10, J12.11, J12.12, J12.13, J13.1, J14.1, J16.2, J16.4, J16.6, J17.1, R20.1, R26.1, R27.1, R32.1, R37.2, S3.1, S4.1, SHLD1.1, U9.7, U9.EPAD, U10.1, U10.15, U10.38, U10.GND1, U10.GNDT1, U10.GNDT2, U10.GNDT3, U10.GNDT4, U10.GNDT5, U10.GNDT6, U10.GNDT7, U10.GNDT8, U11.1, U12.2, U13.1, U13.4, U13.6, U13.9, U14.2, U15.2, U16.6, U16.7, U16.13, U16.EPAD
GND2: C55.2, C56.2, C57.2, C58.2, C59.2, C60.2, C61.2, C62.2, C63.2, C64.2, C65.2, C66.2, C67.2, C68.2, C69.2, C70.2, C71.2, C72.2, C73.2, C74.2, C75.2, C76.2, C77.2, C78.2, C79.2, C80.2, C81.2, D15.C, D16.1, D21.1, J19.GND, J19.GND2, J20.1, J21.6, J21.10, J21.11, J21.12, J21.13, J22.1, J23.1, J25.2, J25.4, J25.6, J26.1, R39.1, R45.1, R46.1, R51.1, R56.2, S5.1, S6.1, SHLD2.1, U17.7, U17.EPAD, U18.1, U18.15, U18.38, U18.GND1, U18.GNDT1, U18.GNDT2, U18.GNDT3, U18.GNDT4, U18.GNDT5, U18.GNDT6, U18.GNDT7, U18.GNDT8, U19.1, U20.2, U21.1, U21.4, U21.6, U21.9, U22.2, U23.2, U24.6, U24.7, U24.13, U24.EPAD
GND3: C82.2, C83.2, C84.2, C85.2, C86.2, C87.2, C88.2, C89.2, C90.2, C91.2, C92.2, C93.2, C94.2, C95.2, C96.2, C97.2, C98.2, C99.2, C100.2, C101.2, C102.2, C103.2, C104.2, C105.2, C106.2, C107.2, C108.2, D22.C, D23.1, D28.1, J28.GND, J28.GND2, J29.1, J30.6, J30.10, J30.11, J30.12, J30.13, J31.1, J32.1, J34.2, J34.4, J34.6, J35.1, R58.1, R64.1, R65.1, R70.1, R75.2, S7.1, S8.1, SHLD3.1, U25.7, U25.EPAD, U26.1, U26.15, U26.38, U26.GND1, U26.GNDT1, U26.GNDT2, U26.GNDT3, U26.GNDT4, U26.GNDT5, U26.GNDT6, U26.GNDT7, U26.GNDT8, U27.1, U28.2, U29.1, U29.4, U29.6, U29.9, U30.2, U31.2, U32.6, U32.7, U32.13, U32.EPAD
GND4: C109.2, C110.2, C111.2, C112.2, C113.2, C114.2, C115.2, C116.2, C117.2, C118.2, C119.2, C120.2, C121.2, C122.2, C123.2, C124.2, C125.2, C126.2, C127.2, C128.2, C129.2, C130.2, C131.2, C132.2, C133.2, C134.2, C135.2, D29.C, D30.1, D35.1, J37.GND, J37.GND2, J38.1, J39.6, J39.10, J39.11, J39.12, J39.13, J40.1, J41.1, J43.2, J43.4, J43.6, J44.1, R77.1, R83.1, R84.1, R89.1, R94.2, S9.1, S10.1, SHLD4.1, U33.7, U33.EPAD, U34.1, U34.15, U34.38, U34.GND1, U34.GNDT1, U34.GNDT2, U34.GNDT3, U34.GNDT4, U34.GNDT5, U34.GNDT6, U34.GNDT7, U34.GNDT8, U35.1, U36.2, U37.1, U37.4, U37.6, U37.9, U38.2, U39.2, U40.6, U40.7, U40.13, U40.EPAD
GND5: C136.2, C137.2, C138.2, C139.2, C140.2, C141.2, C142.2, C143.2, C144.2, C145.2, C146.2, C147.2, C148.2, C149.2, C150.2, C151.2, C152.2, C153.2, C154.2, C155.2, C156.2, C157.2, C158.2, C159.2, C160.2, C161.2, C162.2, D36.C, D37.1, D42.1, J46.GND, J46.GND2, J47.1, J48.6, J48.10, J48.11, J48.12, J48.13, J49.1, J50.1, J52.2, J52.4, J52.6, J53.1, R96.1, R102.1, R103.1, R108.1, R113.2, S11.1, S12.1, SHLD5.1, U41.7, U41.EPAD, U42.1, U42.15, U42.38, U42.GND1, U42.GNDT1, U42.GNDT2, U42.GNDT3, U42.GNDT4, U42.GNDT5, U42.GNDT6, U42.GNDT7, U42.GNDT8, U43.1, U44.2, U45.1, U45.4, U45.6, U45.9, U46.2, U47.2, U48.6, U48.7, U48.13, U48.EPAD
unnamed: J4.B5, R8.2
unnamed: J4.A5, R9.2
unnamed: D1.C, D2.C, D3.C, MEAS.1, MEAS.3
unnamed: Q1.2, R12.1
unnamed: Q1.5, R11.1
unnamed: R19.1, STAT.2
unnamed: D6.4, TP1.1
unnamed: CHG.1, D5.A
unnamed: D5.C, R13.1
unnamed: R13.2, TP3.1, U5.1
unnamed: R14.2, U5.5
unnamed: D6.3, RGB.1
unnamed: D7.A, STAT.1
unnamed: J10.B5, R20.2
unnamed: J10.A5, R27.2
unnamed: I2C.1, R18.1
unnamed: I2C.3, R15.2
unnamed: Q2.2, R30.1
unnamed: Q2.5, R29.1
unnamed: D9.4, TP5.1
unnamed: R32.2, U14.5
unnamed: R31.1, STAT1.2
unnamed: D8.A, STAT1.1
unnamed: I2C1.1, R34.1
unnamed: I2C1.3, R35.2
unnamed: CHG1.1, D10.A
unnamed: D10.C, R33.1
unnamed: R33.2, TP8.1, U14.1
unnamed: D9.3, RGB1.1
unnamed: D11.C, D12.C, D13.C, MEAS1.1, MEAS1.3
unnamed: J19.B5, R39.2
unnamed: J19.A5, R46.2
unnamed: Q3.2, R49.1
unnamed: Q3.5, R48.1
unnamed: D16.4, TP9.1
unnamed: R51.2, U22.5
unnamed: R50.1, STAT2.2
unnamed: D15.A, STAT2.1
unnamed: I2C2.1, R53.1
unnamed: I2C2.3, R54.2
unnamed: CHG2.1, D17.A
unnamed: D17.C, R52.1
unnamed: R52.2, TP12.1, U22.1
unnamed: D16.3, RGB2.1
unnamed: D18.C, D19.C, D20.C, MEAS2.1, MEAS2.3
unnamed: J28.B5, R58.2
unnamed: J28.A5, R65.2
unnamed: Q4.2, R68.1
unnamed: Q4.5, R67.1
unnamed: D23.4, TP13.1
unnamed: R70.2, U30.5
unnamed: R69.1, STAT3.2
unnamed: D22.A, STAT3.1
unnamed: I2C3.1, R72.1
unnamed: I2C3.3, R73.2
unnamed: CHG3.1, D24.A
unnamed: D24.C, R71.1
unnamed: R71.2, TP16.1, U30.1
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

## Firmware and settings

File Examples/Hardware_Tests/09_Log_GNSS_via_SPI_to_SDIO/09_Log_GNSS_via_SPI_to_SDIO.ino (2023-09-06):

// SparkFun DataLogger IoT Test Example
// Tested with Espressif ESP32 v2.0.5 and the "ESP32 Dev Module" board definition

/**********************************************************************************************
 *
 * WARNING!
 * 
 * This is a sketch we wrote to test the DataLogger IoT hardware.
 * Please think very carefully before uploading it to your DataLogger.
 * 
 * You will overwrite the DataLogger firmware, leaving it unable to update or restore itself. 
 * 
 * The DataLogger IoT comes pre-programmed with amazing firmware which can do _so_ much.
 * It is designed to be able to update itself and restore itself if necessary.
 * But it can not do that if you overwrite the firmware with this test sketch.
 * It is just like erasing the restore partition on your computer hard drive.
 * Do not do it - unless you really know what you are doing.
 * 
 * Really. We mean it.
 * 
 * Your friends at SparkFun.
 * 
 * License: MIT. Please see LICENSE.MD for more details
 * 
 **********************************************************************************************/

/*
  This example shows how to configure the u-blox GNSS to send RXM SFRBX and RAWX reports automatically
  and log the data to SD card in UBX format.
  
  This code is written for the DataLogger IoT (DEV-20594)

  Hardware set-up:
  Close the DSEL jumper on the ZED-F9P breakout - to select SPI mode
  Connect:
  DataLogger    : ZED-F9P
  GND             GND
  3V3_SW          3V3
  SCK  (18)       SCK
  PICO (23)       PICO (MOSI)
  POCI (19)       POCI (MISO)
  33              CS

  ** Please note: this example will only work on u-blox ADR or High Precision GNSS or Time Sync products **

  Data is logged in u-blox UBX format.

  Feel like supporting open source hardware?
  Buy a board from SparkFun!
  DataLogger IoT: https://www.sparkfun.com/products/20594
  ZED-F9P RTK2: https://www.sparkfun.com/products/15136
  NEO-M8P RTK: https://www.sparkfun.com/products/15005
*/

#define GNSS_CS 33   // Connect the ZED-F9P CS pin to DataLogger IoT pin 33
#define EN_3V3_SW 32 // The 3.3V_SW regulator Enable pin is connected to D32
#define STAT_LED 25  // The DataLogger IoT STAT LED is connected to pin 25

#include "FS.h"
#include "SD_MMC.h"
File myFile;

#include <SPI.h>
#define spiPort SPI

#include <SparkFun_u-blox_GNSS_Arduino_Library.h> //Click here to get the library: http://librarymanager/All#SparkFun_u-blox_GNSS
SFE_UBLOX_GNSS myGNSS;

#define sdWriteSize 2048     // Write data to the SD card in blocks of n*512 bytes
#define fileBufferSize 65530 // Allocate just under 64KBytes of RAM for UBX message storage
#define navRate 20           // Set the Nav Rate (Frequency) to 20Hz
//#define ubxOnly            // Uncomment this line to log UBX (RAWX and SFRBX) only
uint8_t *myBuffer; // Use myBuffer to hold the data while we write it to SD card

unsigned long lastPrint; // Record when the last Serial print took place

// Note: we'll keep a count of how many SFRBX and RAWX messages arrive - but the count will not be completely accurate.
// If two or more SFRBX messages arrive together as a group and are processed by one call to checkUblox, the count will
// only increase by one.

int numSFRBX = 0; // Keep count of how many SFRBX message groups have been received (see note above)
int numRAWX = 0; // Keep count of how many RAWX message groups have been received (see note above)

// Callback: newSFRBX will be called when new RXM SFRBX data arrives
// See u-blox_structs.h for the full definition of UBX_RXMSFRBX_data_t
//         _____  You can use any name you like for the callback. Use the same name when you call setAutoRXMSFRBXcallback
//        /                  _____  This _must_ be UBX_RXM_SFRBX_data_t
//        |                 /               _____ You can use any name you like for the struct
//        |                 |              /
//        |                 |              |
void newSFRBX(UBX_RXM_SFRBX_data_t *ubxDataStruct)
{
  numSFRBX++; // Increment the count
}

// Callback: newRAWX will be called when new RXM RAWX data arrives
// See u-blox_structs.h for the full definition of UBX_RXMRAWX_data_t
//         _____  You can use any name you like for the callback. Use the same name when you call setAutoRXMRAWXcallback
//        /             _____  This _must_ be UBX_RXM_RAWX_data_t
//        |            /                _____ You can use any name you like for the struct
//        |            |               /
//        |            |               |
void newRAWX(UBX_RXM_RAWX_data_t *ubxDataStruct)
{
  numRAWX++; // Increment the count
}

void setup()
{
  Serial.begin(115200);

  pinMode(STAT_LED, OUTPUT); // Flash the STAT LED each time we write to the SD card
  digitalWrite(STAT_LED, LOW);

  pinMode(GNSS_CS, OUTPUT);
  digitalWrite(GNSS_CS, HIGH);

  spiPort.begin();

  // Do a fake transaction to initialize the SPI pins
  spiPort.beginTransaction(SPISettings(4000000, MSBFIRST, SPI_MODE0));
  spiPort.transfer(0);
  spiPort.endTransaction();

  pinMode(EN_3V3_SW, OUTPUT); // Enable power for the microSD card and GNSS
  digitalWrite(EN_3V3_SW, HIGH);
  
  delay(3000); // Allow time for the GNSS and SD card to start up and for Tera Term to reconnect
  Serial.println(F("SparkFun DataLogger IoT GNSS Logging : SPI and SDIO"));

  // -=-=-=-=-=-=-=-=-=-=-=-=-=-=-=-=-=-=-=-=-=-=-=
  // Initialize the GNSS

  Serial.println(F("Initializing the GNSS..."));

  //myGNSS.enableDebugging(); // Uncomment this line to see helpful debug messages on Serial

  myGNSS.setFileBufferSize(fileBufferSize); // setFileBufferSize must be called _before_ .begin

  // Connect to the u-blox module using SPI port, csPin and speed setting
  // ublox devices generally work up to 5MHz. We'll use 4MHz for this example:
  bool begun = false;
  do
  {
    begun = myGNSS.begin(spiPort, GNSS_CS, 4000000);
    if (!begun)
    {
      Serial.println(F("u-blox GNSS not detected on SPI bus."));
      delay(1000);
    }
  }
  while (!begun);
  
  // -=-=-=-=-=-=-=-=-=-=-=-=-=-=-=-=-=-=-=-=-=-=-=
  // Wait for a 3D fix. Get the date and time for the log file

  //myGNSS.factoryDefault(); delay(5000); // Uncomment this line to reset the module back to its factory defaults

#ifdef ubxOnly
  myGNSS.setSPIOutput(COM_TYPE_UBX); //Set the SPI port to output only UBX
#else
  myGNSS.setSPIOutput(COM_TYPE_UBX | COM_TYPE_NMEA); //Set the SPI port to output both UBX and NMEA messages
#endif

  //myGNSS.saveConfigSelective(VAL_CFG_SUBSEC_IOPORT); //Optional: save (only) the communications port settings to flash and BBR

  Serial.print(F("Waiting for a 3D fix"));

  uint8_t fix = 0;

  do
  {
    fix = myGNSS.getFixType();
    delay(1000);
    Serial.print(F("."));
  }
  while ( fix != 3 ); // Wait for a 3D fix

  Serial.println();

  uint16_t y = myGNSS.getYear();
  uint8_t M = myGNSS.getMonth();
  uint8_t d = myGNSS.getDay();
  uint8_t h = myGNSS.getHour();
  uint8_t m = myGNSS.getMinute();
  uint8_t s = myGNSS.getSecond();

  char szBuffer[40] = {'\0'};
  snprintf(szBuffer, sizeof(szBuffer), "/%04d%02d%02d%02d%02d%02d.ubx", y, M, d, h, m, s);

  Serial.println(F("GNSS initialized."));

  // -=-=-=-=-=-=-=-=-=-=-=-=-=-=-=-=-=-=-=-=-=-=-=
  // Initialize the SD card. Open the log file

  Serial.println(F("Initializing SD card..."));

  // Begin the SD card
  if(!SD_MMC.begin())
  {
    Serial.println(F("Card mount failed. Freezing..."));
    while(1);
  }

  // Open the log file for writing
  Serial.printf("Log file is: %s\r\n", szBuffer);
  myFile = SD_MMC.open((const char *)szBuffer, FILE_WRITE);
  if(!myFile)
  {
    Serial.println(F("Failed to open log file for writing. Freezing..."));
    while(1);
  }

  Serial.println(F("SD card initialized."));

  // -=-=-=-=-=-=-=-=-=-=-=-=-=-=-=-=-=-=-=-=-=-=-=
  // Wait for a key press

  while (Serial.available()) // Make sure the Serial buffer is empty
  {
    Serial.read();
  }

  Serial.println(F("Press any key to start logging."));

  while (!Serial.available()) // Wait for the user to press a key
  {
    ; // Do nothing
  }

  delay(100); // Wait, just in case multiple characters were sent

  while (Serial.available()) // Empty the Serial buffer
  {
    Serial.read();
  }

  // -=-=-=-=-=-=-=-=-=-=-=-=-=-=-=-=-=-=-=-=-=-=-=
  // Enable RAWX and SFRBX

  myGNSS.setAutoRXMSFRBXcallbackPtr(&newSFRBX); // Enable automatic RXM SFRBX messages with callback to newSFRBX

  myGNSS.logRXMSFRBX(); // Enable RXM SFRBX data logging

  myGNSS.setAutoRXMRAWXcallbackPtr(&newRAWX); // Enable automatic RXM RAWX messages with callback to newRAWX

  myGNSS.logRXMRAWX(); // Enable RXM RAWX data logging

  myBuffer = new uint8_t[sdWriteSize]; // Create our own buffer to hold the data while we write it to SD card  

#ifndef ubxOnly
  myGNSS.enableNMEAMessage(UBX_NMEA_GGA, COM_PORT_SPI, navRate); // Ensure the GxGGA (Global positioning system fix data) message is enabled. Send every second.
  myGNSS.enableNMEAMessage(UBX_NMEA_GSA, COM_PORT_SPI, navRate); // Ensure the GxGSA (GNSS DOP and Active satellites) message is enabled. Send every second.
  myGNSS.enableNMEAMessage(UBX_NMEA_GSV, COM_PORT_SPI, navRate); // Ensure the GxGSV (GNSS satellites in view) message is enabled. Send every second.
  myGNSS.enableNMEAMessage(UBX_NMEA_GST, COM_PORT_SPI, navRate); // Ensure the GxGST (Position error statistics) message is enabled. Send every second.
  myGNSS.enableNMEAMessage(UBX_NMEA_RMC, COM_PORT_SPI, navRate); // Ensure the GxRMC (Recommended minimum: position, velocity and time) message is enabled. Send every second.
  myGNSS.setNMEALoggingMask(SFE_UBLOX_FILTER_NMEA_GGA | SFE_UBLOX_FILTER_NMEA_GSA | SFE_UBLOX_FILTER_NMEA_GSV | SFE_UBLOX_FILTER_NMEA_GST | SFE_UBLOX_FILTER_NMEA_RMC); // Log only these NMEA messages
#endif

  myGNSS.setNavigationFrequency(navRate); // Set navigation rate

  Serial.println(F("Press any key to stop logging."));

  lastPrint = millis(); // Initialize lastPrint
}

void loop()
{
  // =-=-=-=-=-=-=-=-=-=-=-=-=-=-=-=-=-=-=-=-

  myGNSS.checkUblox(); // Check for the arrival of new data and process it.
  myGNSS.checkCallbacks(); // Check if any callbacks are waiting to be processed.

  // =-=-=-=-=-=-=-=-=-=-=-=-=-=-=-=-=-=-=-=-

  while (myGNSS.fileBufferAvailable() >= sdWriteSize) // Check to see if we have at least sdWriteSize waiting in the buffer
  {
    digitalWrite(STAT_LED, HIGH); // Flash the STAT LED each time we write to the SD card

    myGNSS.extractFileBufferData(myBuffer, sdWriteSize); // Extract exactly sdWriteSize bytes from the UBX file buffer and put them into myBuffer

    myFile.write(myBuffer, sdWriteSize); // Write exactly sdWriteSize bytes from myBuffer to the ubxDataFile on the SD card

    // In case the SD writing is slow or there is a lot of data to write, keep checking for the arrival of new data
    myGNSS.checkUblox(); // Check for the arrival of new data and process it.
    myGNSS.checkCallbacks(); // Check if any callbacks are waiting to be processed.

    digitalWrite(STAT_LED, LOW); // Turn the STAT LED off again
  }

  // =-=-=-=-=-=-=-=-=-=-=-=-=-=-=-=-=-=-=-=-

  if (millis() > (lastPrint + 1000)) // Print the message count once per second
  {
    uint16_t maxBufferBytes = myGNSS.getMaxFileBufferAvail(); // Get how full the file buffer has been (not how full it is now)
    float bufferHigh = 100.0 * (float)maxBufferBytes / (float)fileBufferSize;

    Serial.print(F("Message groups received: SFRBX: ")); // Print how many message groups have been received (see note above)
    Serial.print(numSFRBX);
    Serial.print(F(" RAWX: "));
    Serial.print(numRAWX);
    Serial.print(F("  \tBuffer high tide: "));
    Serial.print(bufferHigh, 1); // It is a fun thing to watch how full the buffer gets
    if (bufferHigh > 90.)
      Serial.println(F("%!!"));
    else if (bufferHigh > 80.)
      Serial.println(F("%!"));
    else
      Serial.println(F("%"));

    lastPrint = millis(); // Update lastPrint
  }

  // =-=-=-=-=-=-=-=-=-=-=-=-=-=-=-=-=-=-=-=-

  if (Serial.available()) // Check if the user wants to stop logging
  {
    uint16_t remainingBytes = myGNSS.fileBufferAvailable(); // Check if there are any bytes remaining in the file buffer

    while (remainingBytes > 0) // While there is still data in the file buffer
    {
      digitalWrite(STAT_LED, HIGH); // Flash the STAT LED while we write to the SD card

      uint16_t bytesToWrite = remainingBytes; // Write the remaining bytes to SD card sdWriteSize bytes at a time
      if (bytesToWrite > sdWriteSize)
      {
        bytesToWrite = sdWriteSize;
      }

      myGNSS.extractFileBufferData(myBuffer, bytesToWrite); // Extract bytesToWrite bytes from the UBX file buffer and put them into myBuffer

      myFile.write(myBuffer, bytesToWrite); // Write bytesToWrite bytes from myBuffer to the ubxDataFile on the SD card

      remainingBytes -= bytesToWrite; // Decrement remainingBytes
    }

    digitalWrite(STAT_LED, LOW); // Turn the STAT LED off

    myFile.close(); // Close the data file

    myGNSS.setNavigationFrequency(1); // Set navigation rate to 1Hz

    myGNSS.disableMessage(UBX_CLASS_RXM, UBX_RXM_RAWX, COM_PORT_SPI);
    myGNSS.disableMessage(UBX_CLASS_RXM, UBX_RXM_SFRBX, COM_PORT_SPI);

    myGNSS.setSPIOutput(COM_TYPE_UBX | COM_TYPE_NMEA); // Re-enable NMEA

    Serial.println(F("Logging stopped. Freezing..."));
    while(1); // Do nothing more
  }

  // =-=-=-=-=-=-=-=-=-=-=-=-=-=-=-=-=-=-=-=-
}

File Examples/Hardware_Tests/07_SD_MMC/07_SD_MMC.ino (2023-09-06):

// SparkFun DataLogger IoT Test Example
// Tested with Espressif ESP32 v2.0.5 and the "ESP32 Dev Module" board definition

/**********************************************************************************************
 *
 * WARNING!
 * 
 * This is a sketch we wrote to test the DataLogger IoT hardware.
 * Please think very carefully before uploading it to your DataLogger.
 * 
 * You will overwrite the DataLogger firmware, leaving it unable to update or restore itself. 
 * 
 * The DataLogger IoT comes pre-programmed with amazing firmware which can do _so_ much.
 * It is designed to be able to update itself and restore itself if necessary.
 * But it can not do that if you overwrite the firmware with this test sketch.
 * It is just like erasing the restore partition on your computer hard drive.
 * Do not do it - unless you really know what you are doing.
 * 
 * Really. We mean it.
 * 
 * Your friends at SparkFun.
 * 
 * License: MIT. Please see LICENSE.MD for more details
 * 
 **********************************************************************************************/

// Based on: https://github.com/espressif/arduino-esp32/blob/master/libraries/SD_MMC/examples/SDMMC_Test/SDMMC_Test.ino

#define EN_3V3_SW 32 // The 3.3V_SW regulator Enable pin is connected to D32

#include "FS.h"
#include "SD_MMC.h"

void listDir(fs::FS &fs, const char * dirname, uint8_t levels){
    Serial.printf("Listing directory: %s\n", dirname);

    File root = fs.open(dirname);
    if(!root){
        Serial.println("Failed to open directory");
        return;
    }
    if(!root.isDirectory()){
        Serial.println("Not a directory");
        return;
    }

    File file = root.openNextFile();
    while(file){
        if(file.isDirectory()){
            Serial.print("  DIR : ");
            Serial.println(file.name());
            if(levels){
                listDir(fs, file.path(), levels -1);
            }
        } else {
            Serial.print("  FILE: ");
            Serial.print(file.name());
            Serial.print("  SIZE: ");
            Serial.println(file.size());
        }
        file = root.openNextFile();
    }
}

void createDir(fs::FS &fs, const char * path){
    Serial.printf("Creating Dir: %s\n", path);
    if(fs.mkdir(path)){
        Serial.println("Dir created");
    } else {
        Serial.println("mkdir failed");
    }
}

void removeDir(fs::FS &fs, const char * path){
    Serial.printf("Removing Dir: %s\n", path);
    if(fs.rmdir(path)){
        Serial.println("Dir removed");
    } else {
        Serial.println("rmdir failed");
    }
}

void readFile(fs::FS &fs, const char * path){
    Serial.printf("Reading file: %s\n", path);

    File file = fs.open(path);
    if(!file){
        Serial.println("Failed to open file for reading");
        return;
    }

    Serial.print("Read from file: ");
    while(file.available()){
        Serial.write(file.read());
    }
}

void writeFile(fs::FS &fs, const char * path, const char * message){
    Serial.printf("Writing file: %s\n", path);

    File file = fs.open(path, FILE_WRITE);
    if(!file){
        Serial.println("Failed to open file for writing");
        return;
    }
    if(file.print(message)){
        Serial.println("File written");
    } else {
        Serial.println("Write failed");
    }
}

void appendFile(fs::FS &fs, const char * path, const char * message){
    Serial.printf("Appending to file: %s\n", path);

    File file = fs.open(path, FILE_APPEND);
    if(!file){
        Serial.println("Failed to open file for appending");
        return;
    }
    if(file.print(message)){
        Serial.println("Message appended");
    } else {
        Serial.println("Append failed");
    }
}

void renameFile(fs::FS &fs, const char * path1, const char * path2){
    Serial.printf("Renaming file %s to %s\n", path1, path2);
    if (fs.rename(path1, path2)) {
        Serial.println("File renamed");
    } else {
        Serial.println("Rename failed");
    }
}

void deleteFile(fs::FS &fs, const char * path){
    Serial.printf("Deleting file: %s\n", path);
    if(fs.remove(path)){
        Serial.println("File deleted");
    } else {
        Serial.println("Delete failed");
    }
}

void testFileIO(fs::FS &fs, const char * path){
    File file = fs.open(path);
    static uint8_t buf[512];
    size_t len = 0;
    uint32_t start = millis();
    uint32_t end = start;
    if(file){
        len = file.size();
        size_t flen = len;
        start = millis();
        while(len){
            size_t toRead = len;
            if(toRead > 512){
                toRead = 512;
            }
            file.read(buf, toRead);
            len -= toRead;
        }
        end = millis() - start;
        Serial.printf("%u bytes read for %u ms\n", flen, end);
        file.close();
    } else {
        Serial.println("Failed to open file for reading");
    }


    file = fs.open(path, FILE_WRITE);
    if(!file){
        Serial.println("Failed to open file for writing");
        return;
    }

    size_t i;
    start = millis();
    for(i=0; i<2048; i++){
        file.write(buf, 512);
    }
    end = millis() - start;
    Serial.printf("%u bytes written for %u ms\n", 2048 * 512, end);
    file.close();
}

void setup()
{
  pinMode(EN_3V3_SW, OUTPUT); // Enable power for the microSD card
  digitalWrite(EN_3V3_SW, HIGH);

  delay(1000); // Allow time for the SD card to start up

  Serial.begin(115200);
  if(!SD_MMC.begin()){
      Serial.println("Card Mount Failed");
      return;
  }
  
  uint8_t cardType = SD_MMC.cardType();

  if(cardType == CARD_NONE){
      Serial.println("No SD_MMC card attached");
      return;
  }

  Serial.print("SD_MMC Card Type: ");
  if(cardType == CARD_MMC){
      Serial.println("MMC");
  } else if(cardType == CARD_SD){
      Serial.println("SDSC");
  } else if(cardType == CARD_SDHC){
      Serial.println("SDHC");
  } else {
      Serial.println("UNKNOWN");
  }

  uint64_t cardSize = SD_MMC.cardSize() / (1024 * 1024);
  Serial.printf("SD_MMC Card Size: %lluMB\n", cardSize);

  listDir(SD_MMC, "/", 0);
  createDir(SD_MMC, "/mydir");
  listDir(SD_MMC, "/", 0);
  removeDir(SD_MMC, "/mydir");
  listDir(SD_MMC, "/", 2);
  writeFile(SD_MMC, "/hello.txt", "Hello ");
  appendFile(SD_MMC, "/hello.txt", "World!\n");
  readFile(SD_MMC, "/hello.txt");
  deleteFile(SD_MMC, "/foo.txt");
  renameFile(SD_MMC, "/hello.txt", "/foo.txt");
  readFile(SD_MMC, "/foo.txt");
  testFileIO(SD_MMC, "/test.txt");
  Serial.printf("Total space: %lluMB\n", SD_MMC.totalBytes() / (1024 * 1024));
  Serial.printf("Used space: %lluMB\n", SD_MMC.usedBytes() / (1024 * 1024));
}

void loop()
{
  // Nothing to do here...
}

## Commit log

2023-05-03 Update board for DataLogger IoT
    Remove IMU and associated passives.
    Remove MAG and associated passives.
    Populate C31 with 100n.
    Add MEAS jumper.
    Set PWREN PDR to 10k from 100k.
    Add HW versioning circuit.
    Replace RGB LED with Right-Angle RGB LED.
    [SparkFun_DataLogger_IoT.brd, SparkFun_DataLogger_IoT.sch]
2023-05-04 Pre-Design Review updates
    Add 9.1k Res for hardware versioning.
    Move MEAS to be on grid.
    Shuffle diodes around a little.
    Move silk to fill gaps.
    Change LED bias resistor to meet standards.
    Made HW versioning be on A7 to match RTK designs.
    Replaced A7 breakout with D5.
    Relabeled silk.
    Added silk to RGB LED.
    [SparkFun_DataLogger_IoT.brd, SparkFun_DataLogger_IoT.sch]
2023-05-04 Added Panelization files.
    [SparkFun_DataLogger_IoT-Panel.GBL, SparkFun_DataLogger_IoT-Panel.GBO, SparkFun_DataLogger_IoT-Panel.GBP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]
2023-05-05 Post design review updates.
    Change BO silk for D5.
    Remove unused PURs.
    Clean up wire stubs.
    Remove GND guard trace.
    Add GND vias near switching vias.
    Renumber Schematic.
    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
    [SparkFun_DataLogger_IoT-Panel.GBL, SparkFun_DataLogger_IoT-Panel.GBO, SparkFun_DataLogger_IoT-Panel.GBS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]
2023-05-11 Added Fuel Gauge I2C address.
    [DataLogger_IoT_Enclosure v24.step, SparkFun_DataLogger_IoT.sch]
2023-07-11 Update for v11 PCB
    Removed OSHW logo.
    [SparkFun_DataLogger_IoT-Panel.brd, SparkFun_DataLogger_IoT.brd, SparkFun_DataLogger_IoT.sch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]
2023-07-17 Condensed Schematic.
    [SparkFun_DataLogger_IoT.sch]
2023-07-18 NP unused resistors
    [SparkFun_DataLogger_IoT.brd, SparkFun_DataLogger_IoT.sch]
2023-07-19 Update VREG
    [SparkFun_DataLogger_IoT.brd, SparkFun_DataLogger_IoT.sch]
2023-09-06 Delete enclosure folder.
    Unused.
    [DataLogger_IoT_Enclosure v24.step]
2023-09-06 Restructure HW Tests
    Removed IMU/MAG tests. Renamed other tests for ordering. Removed unnecessary sections of kept tests. Removed redundant deep sleep example.

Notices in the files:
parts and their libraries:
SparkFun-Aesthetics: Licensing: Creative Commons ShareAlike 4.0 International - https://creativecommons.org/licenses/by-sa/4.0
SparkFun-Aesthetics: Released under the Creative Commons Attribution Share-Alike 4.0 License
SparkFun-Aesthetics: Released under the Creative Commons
